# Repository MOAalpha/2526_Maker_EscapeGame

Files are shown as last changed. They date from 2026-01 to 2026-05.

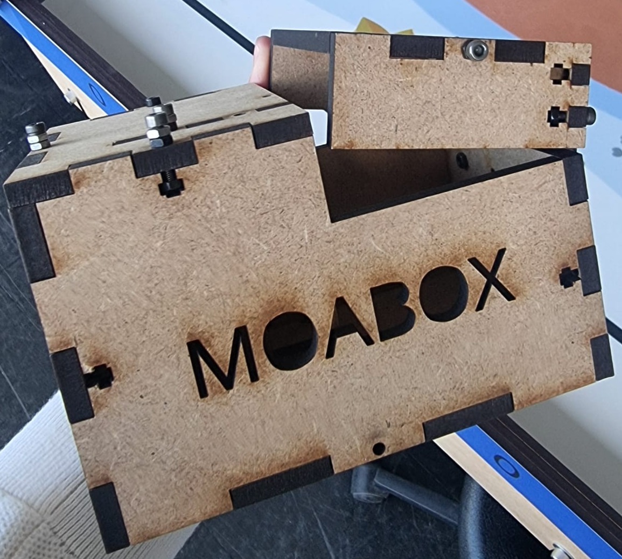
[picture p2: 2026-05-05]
LIVRABLES/USELESS_BOX.jpg

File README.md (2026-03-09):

Projet de GHERRAS M.A., dans le cadre de l'option MAKER 2526.
# **<u>EscapeGame</u>**

Ceci est un projet personnel. L'objectif est de créer une boîte avec différentes énigmes, en mettant en oeuvre différentes compétences apprises, entre la Conception Assistée par Ordinateur (CAO) jusqu'à la fabrication d'un PCB.

## Synopsis

*Une épidémie ravage le monde. Personne n'est à l'abri. Environ 10 000 000 de personnes succombent chaque seconde. Le virus possède une forte volatilité et tue en quelques jours. Le docteur Frank MaBoule, après avoir utilisé sa fille comme cobaye,  a créé un remède. Sa fille ayant succombé, il décida de cacher son remède.Sauriez-vous être le héros qui sauvera ~~le monde~~ votre peau ? Voici les épreuves qui vous attendent :*

### 1. FIND A CODE 
Pour ouvrir la première porte, il faut résoudre une énigme très classique consistant à reconstituer une séquence sur un damier de 4x4 symbolisé par 16 écrans.

### 2. DRESS or LESS 

Pour la deuxième porte, l'idée est de vêtir 3 personnages avec le bon chapeau, pull et pentalon, à l'aide de capteurs RFID. Pour cela, une description incomplète sera fournie à travers l'écran principale.

### 3. CHOOSE THE HERO

Parmi les 3 personnages, un seul cache le remède. Vous aurez leur témoignage pour savoir qui possède le remède.

## Matériel (liste actuelle non exhaustive):

> - 1 écran 15cmx10cm tactile (moniteur principale) [de ce type-là](https://www.amazon.fr/Tactile-Fabricant-Bricolage-Internet-%C3%A9lectrique/dp/B0BWNQKWJR)
> - 16 écrans de 4x4 ?
> - Actionneurs pour portes ? 
> - PLA pour les personnages
> - tissu pour les vêtements
> - ~Capteurs RFID miniatures ?~
> - [Capteurs magnétiques, reed switchs](https://www.amazon.fr/Gebildet-interrupteurs-Plastique-Contact-Aimant/dp/B07Z4RR4QV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)
> - *A suivre...*

## Planning prévisionnel 

| Séance | Action prévue |
|---|---|
| Lundi 16 février 2026 |  Conception des énigmes + Début schématique PCB |
| Jeudi 19 février 2026 | Choix des composants(Ecrans, Rasperry Pi/STM) + Suite PCB |
| Lundi 9 mars 2026 | Début conception mécanique (Plan de la boite, portes, personnages...) |
| Jeudi 12 mars 2026 | Découpe laser pour la boîte et premières impressions de pièces |
| Lundi 16 mars 2026 | Test PCB |
| Jeudi 19 mars 2026 | Setup capteurs RFID + Ecrans principales |
| Lundi 23 mars 2026 |  Améliorations + Correction |
| Jeudi 26 mars 2026 |  Code sur STM/Rasberry Pi |
| Lundi 30 mars 2026 | Tests / A voir |
| Jeudi 2 avril 2026 | A voir |
| Jeudi 9 avril 2026 |  Possibilité de rajouter des énigmes si tout fonctionne. / Création chatbot pour l'énigme des personnages si le temps le permet. |
| Lundi 13 avril 2026 | A voir |

GANTT : (*IA MADE, for visual*)

```mermaid

gantt
    title Planning du projet (février – avril 2026)
    dateFormat  YYYY-MM-DD
    axisFormat  %d/%m

    section Conception
    Conception des énigmes + schéma PCB         :a1, 2026-02-16, 3d
    Choix composants + suite PCB                :a2, after a1, 3d

    section Mécanique
    Conception mécanique (boîte, portes, persos):b1, 2026-03-09, 4d
    Découpe laser + impressions pièces          :b2, after b1, 3d

    section Électronique
    Test PCB                                    :c1, after a2, 2d
    Setup capteurs RFID + écrans principaux     :c2, after c1, 3d

    section Développement
    Améliorations + corrections                 :d1, after c2, 3d
    Code sur STM / Raspberry Pi                 :d2, after d1, 4d

    section Tests & ajustements
    Tests généraux                              :e1, after d2, 3d
    Ajustements techniques                     :e2, after e1, 3d

    section Extensions (optionnel)
    Ajout d’énigmes / chatbot personnages       :f1, after e2, 4d

    section Final
    Finalisation & préparation soutenance       :g1, after f1, 2d

```

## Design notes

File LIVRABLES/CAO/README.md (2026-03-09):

Voici les captures d'écran des éléments réalisés sur Onshape : https://cad.onshape.com/documents/aa734c8ff76d5fbc18c7c107/w/db248731c732559cfe28cdcf/e/f61cb79261a09111bf038288

> - Protections Coins : 

Capture d'écran 2026-01-21 232816

> - Support téléphone : 

 Capture d'écran 2026-01-21 232552

> - Torticolis : 
Capture d'écran 2026-01-21 232736

> - Ciseaux : 
Capture d'écran 2026-01-21 232327

> - Ressort :
Capture d'écran 2026-01-21 232856

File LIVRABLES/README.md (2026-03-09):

Stockage des travaux effectués (et présentables) pendant les séances "Découverte"

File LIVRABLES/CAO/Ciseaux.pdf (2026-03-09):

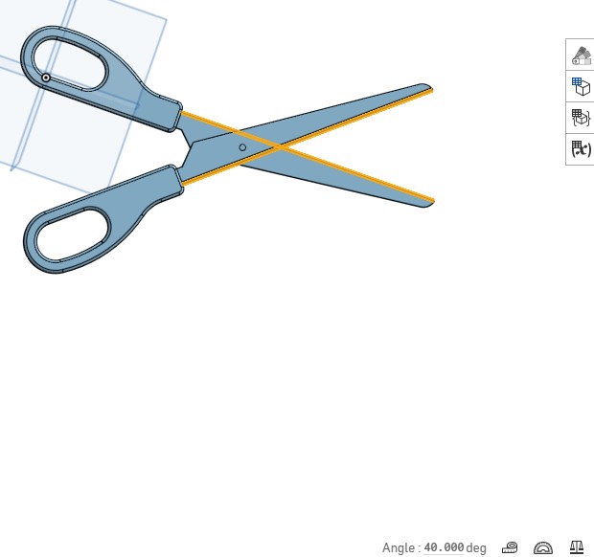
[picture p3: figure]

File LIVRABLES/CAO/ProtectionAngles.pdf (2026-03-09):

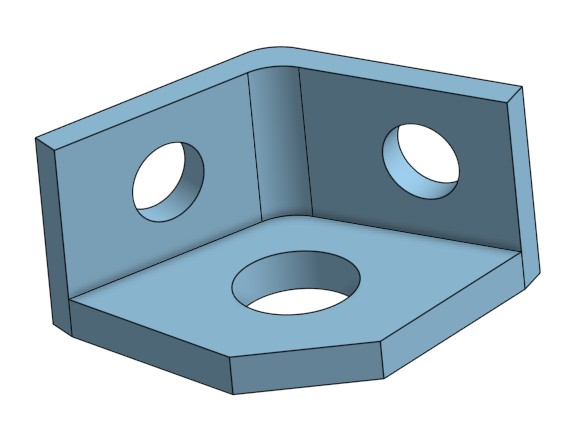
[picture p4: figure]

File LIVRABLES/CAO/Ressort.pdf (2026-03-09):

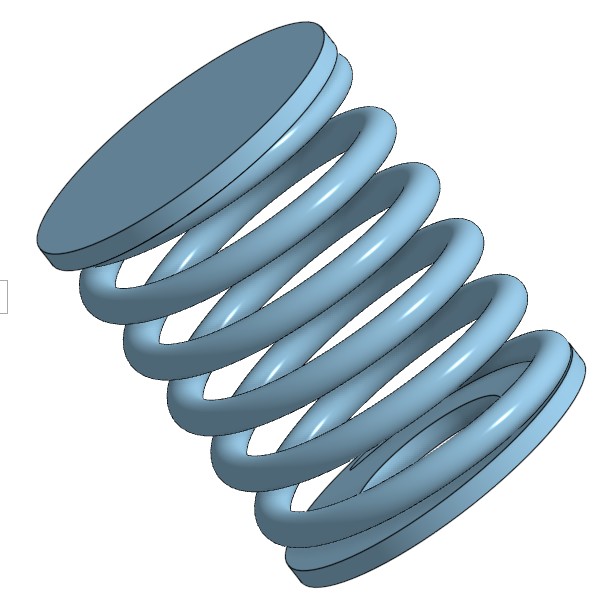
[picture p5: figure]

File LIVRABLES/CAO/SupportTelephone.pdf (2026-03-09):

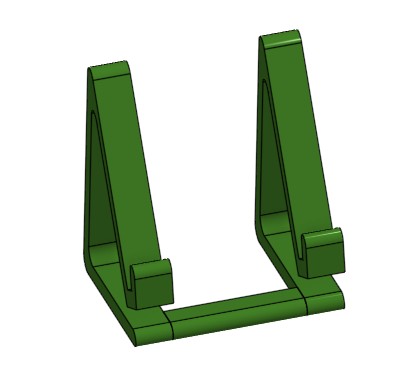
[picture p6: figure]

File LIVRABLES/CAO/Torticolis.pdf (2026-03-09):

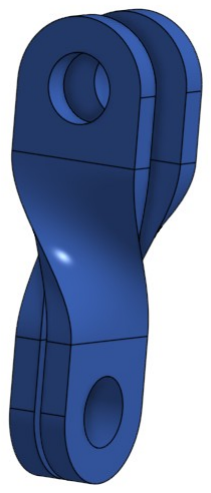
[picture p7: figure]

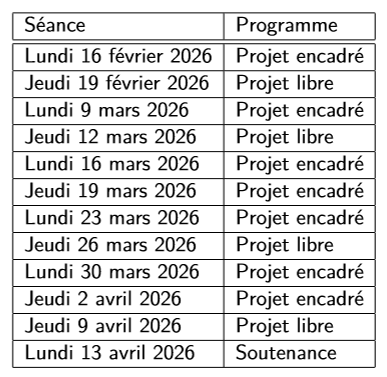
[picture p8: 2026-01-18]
image.png

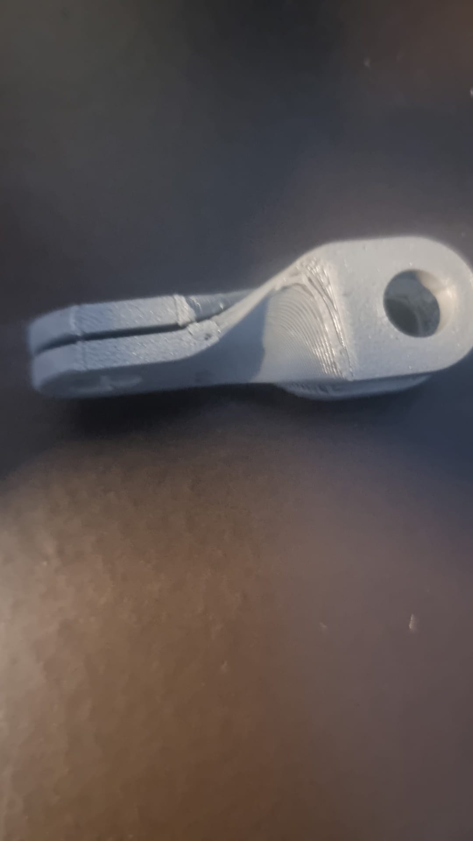
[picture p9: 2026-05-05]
LIVRABLES/Impression3D-Face2.jpeg

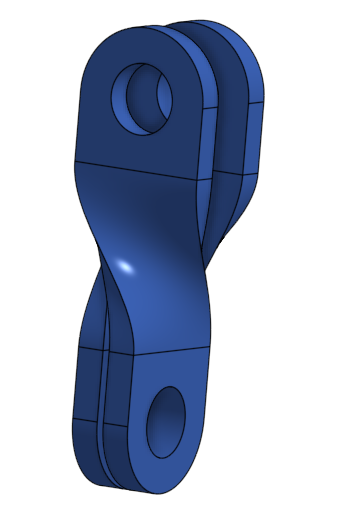
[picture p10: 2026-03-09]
LIVRABLES/CAO/Capture d'écran 2026-01-21 232736.png

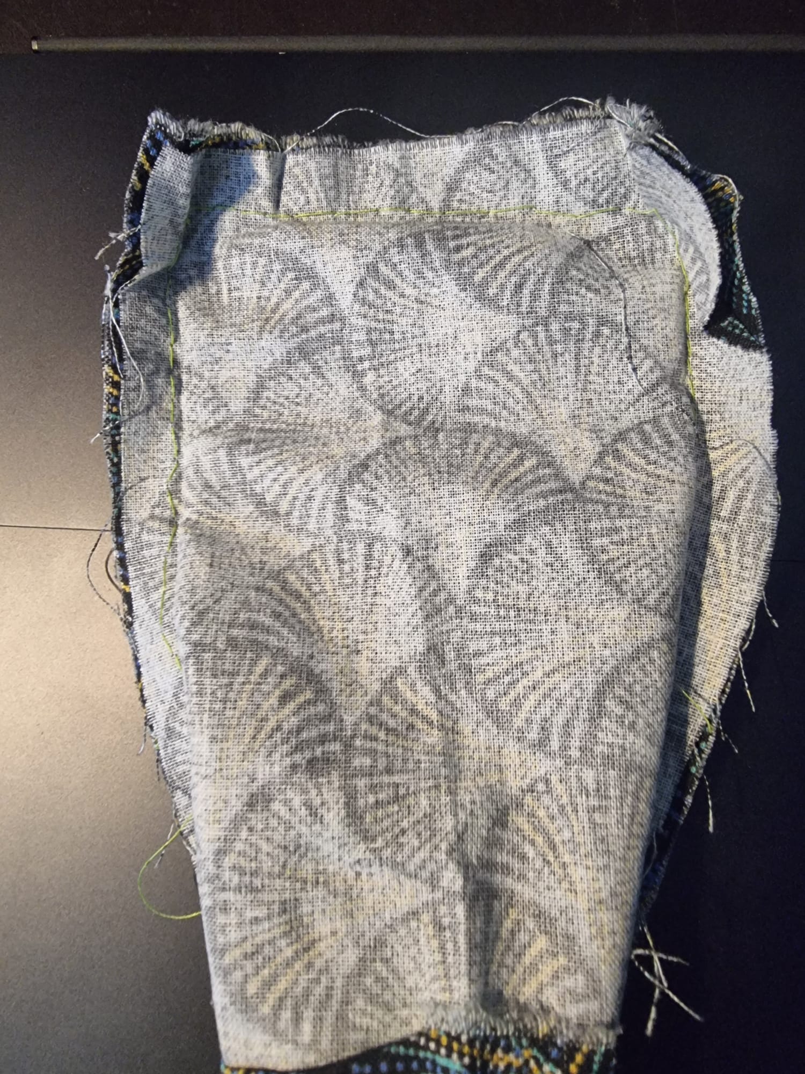
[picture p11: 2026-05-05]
LIVRABLES/Couture-Intérieur.jpeg

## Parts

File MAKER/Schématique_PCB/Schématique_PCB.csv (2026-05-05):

Reference | Qty | Value | DNP | Exclude from BOM | Exclude from Board | Footprint | Datasheet
C1,C2,C9,C10 | 4 | 1u |  |  |  | Capacitor_SMD:C_0805_2012Metric_Pad1.18x1.45mm_HandSolder | ~
C3,C4,C5,C6,C18 | 5 | 100n |  |  |  | Capacitor_SMD:C_0805_2012Metric_Pad1.18x1.45mm_HandSolder | ~
C7 | 1 | 4.7u |  |  |  | Capacitor_SMD:C_0805_2012Metric_Pad1.18x1.45mm_HandSolder | ~
C8,C11,C12,C13,C14,C15,C16,C19 | 8 | 10n |  |  |  | Capacitor_SMD:C_0805_2012Metric_Pad1.18x1.45mm_HandSolder | ~
C17 | 1 | 10u |  |  |  | Capacitor_SMD:C_0805_2012Metric_Pad1.18x1.45mm_HandSolder | ~
D1,D2 | 2 | LED |  |  |  | LED_SMD:LED_0805_2012Metric_Pad1.15x1.40mm_HandSolder | ~
H1,H2,H3,H4 | 4 | MountingHole_Pad |  | Exclure de la Liste du Matériel |  | MountingHole:MountingHole_3.2mm_M3_DIN965_Pad | ~
J1 | 1 | TS1 |  |  |  | Connector_PinHeader_2.54mm:PinHeader_1x03_P2.54mm_Vertical | ~
J2 | 1 | 3.7V |  |  |  | Connector_JST:JST_PH_B2B-PH-K_1x02_P2.00mm_Vertical | ~
J3 | 1 | TS2 |  |  |  | Connector_PinHeader_2.54mm:PinHeader_1x03_P2.54mm_Vertical | ~
J4 | 1 | TS3 |  |  |  | Connector_PinHeader_2.54mm:PinHeader_1x03_P2.54mm_Vertical | ~
J5 | 1 | TS4 |  |  |  | Connector_PinHeader_2.54mm:PinHeader_1x03_P2.54mm_Vertical | ~
J6 | 1 | TS5 |  |  |  | Connector_PinHeader_2.54mm:PinHeader_1x03_P2.54mm_Vertical | ~
J7 | 1 | TS6 |  |  |  | Connector_PinHeader_2.54mm:PinHeader_1x03_P2.54mm_Vertical | ~
J8 | 1 | TS7 |  |  |  | Connector_PinHeader_2.54mm:PinHeader_1x03_P2.54mm_Vertical | ~
J9 | 1 | TS8 |  |  |  | Connector_PinHeader_2.54mm:PinHeader_1x03_P2.54mm_Vertical | ~
J10 | 1 | TS9 |  |  |  | Connector_PinHeader_2.54mm:PinHeader_1x03_P2.54mm_Vertical | ~
J11,J12,J13,J14,J15,J16 | 6 | Conn_01x02_Pin |  |  |  | Connector_PinHeader_2.54mm:PinHeader_1x02_P2.54mm_Vertical | ~
J17 | 1 | Screen |  |  |  | Connector_PinSocket_2.54mm:PinSocket_1x09_P2.54mm_Vertical | ~
J18 | 1 | SD_Card |  |  |  | Connector_PinSocket_2.54mm:PinSocket_1x05_P2.54mm_Vertical | ~
J19 | 1 | Conn_ST_STDC14 |  |  |  | Connector_IDC:IDC-Header_2x07_P2.54mm_Vertical | https://www.st.com/content/ccc/resource/technical/document/user_manual/group1/99/49/91/b6/b2/3a/46/e5/DM00526767/files/DM00526767.pdf/jcr:content/translations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
PS1 | 1 | BU33SD5WG-TR |  |  |  | BU33SD5WG-TR:SOT95P280X125-5N
R1,R3 | 2 | 330 |  |  |  | Resistor_SMD:R_0805_2012Metric_Pad1.20x1.40mm_HandSolder | ~
R2,R12,R13,R14,R15,R16 | 6 | 1K |  |  |  | Resistor_SMD:R_0805_2012Metric_Pad1.20x1.40mm_HandSolder | ~
R4,R5,R6,R7,R8,R9 | 6 | 100 |  |  |  | Resistor_SMD:R_0805_2012Metric_Pad1.20x1.40mm_HandSolder | ~
R10,R11 | 2 | 10k |  |  |  | Resistor_SMD:R_0805_2012Metric_Pad1.20x1.40mm_HandSolder | ~
SW1 | 1 | SW_Push |  |  |  | Button_Switch_SMD:SW_SPST_B3U-1000P | ~
U1 | 1 | STM32G474RET6 |  |  |  | Package_QFP:LQFP-64_10x10mm_P0.5mm | https://www.st.com/resource/en/datasheet/stm32g474re.pdf

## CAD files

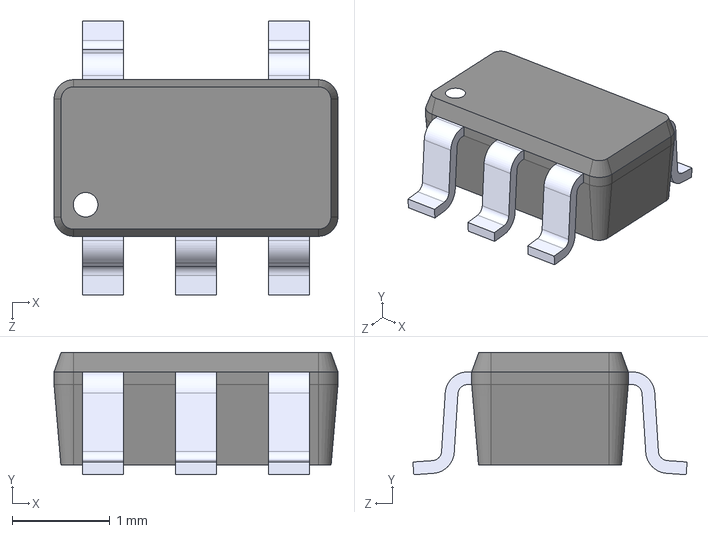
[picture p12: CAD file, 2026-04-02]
MAKER/Symbols/BU33SD5WG-TR/BU33SD5WG-TR.step
2.90 x 1.25 x 2.80 mm

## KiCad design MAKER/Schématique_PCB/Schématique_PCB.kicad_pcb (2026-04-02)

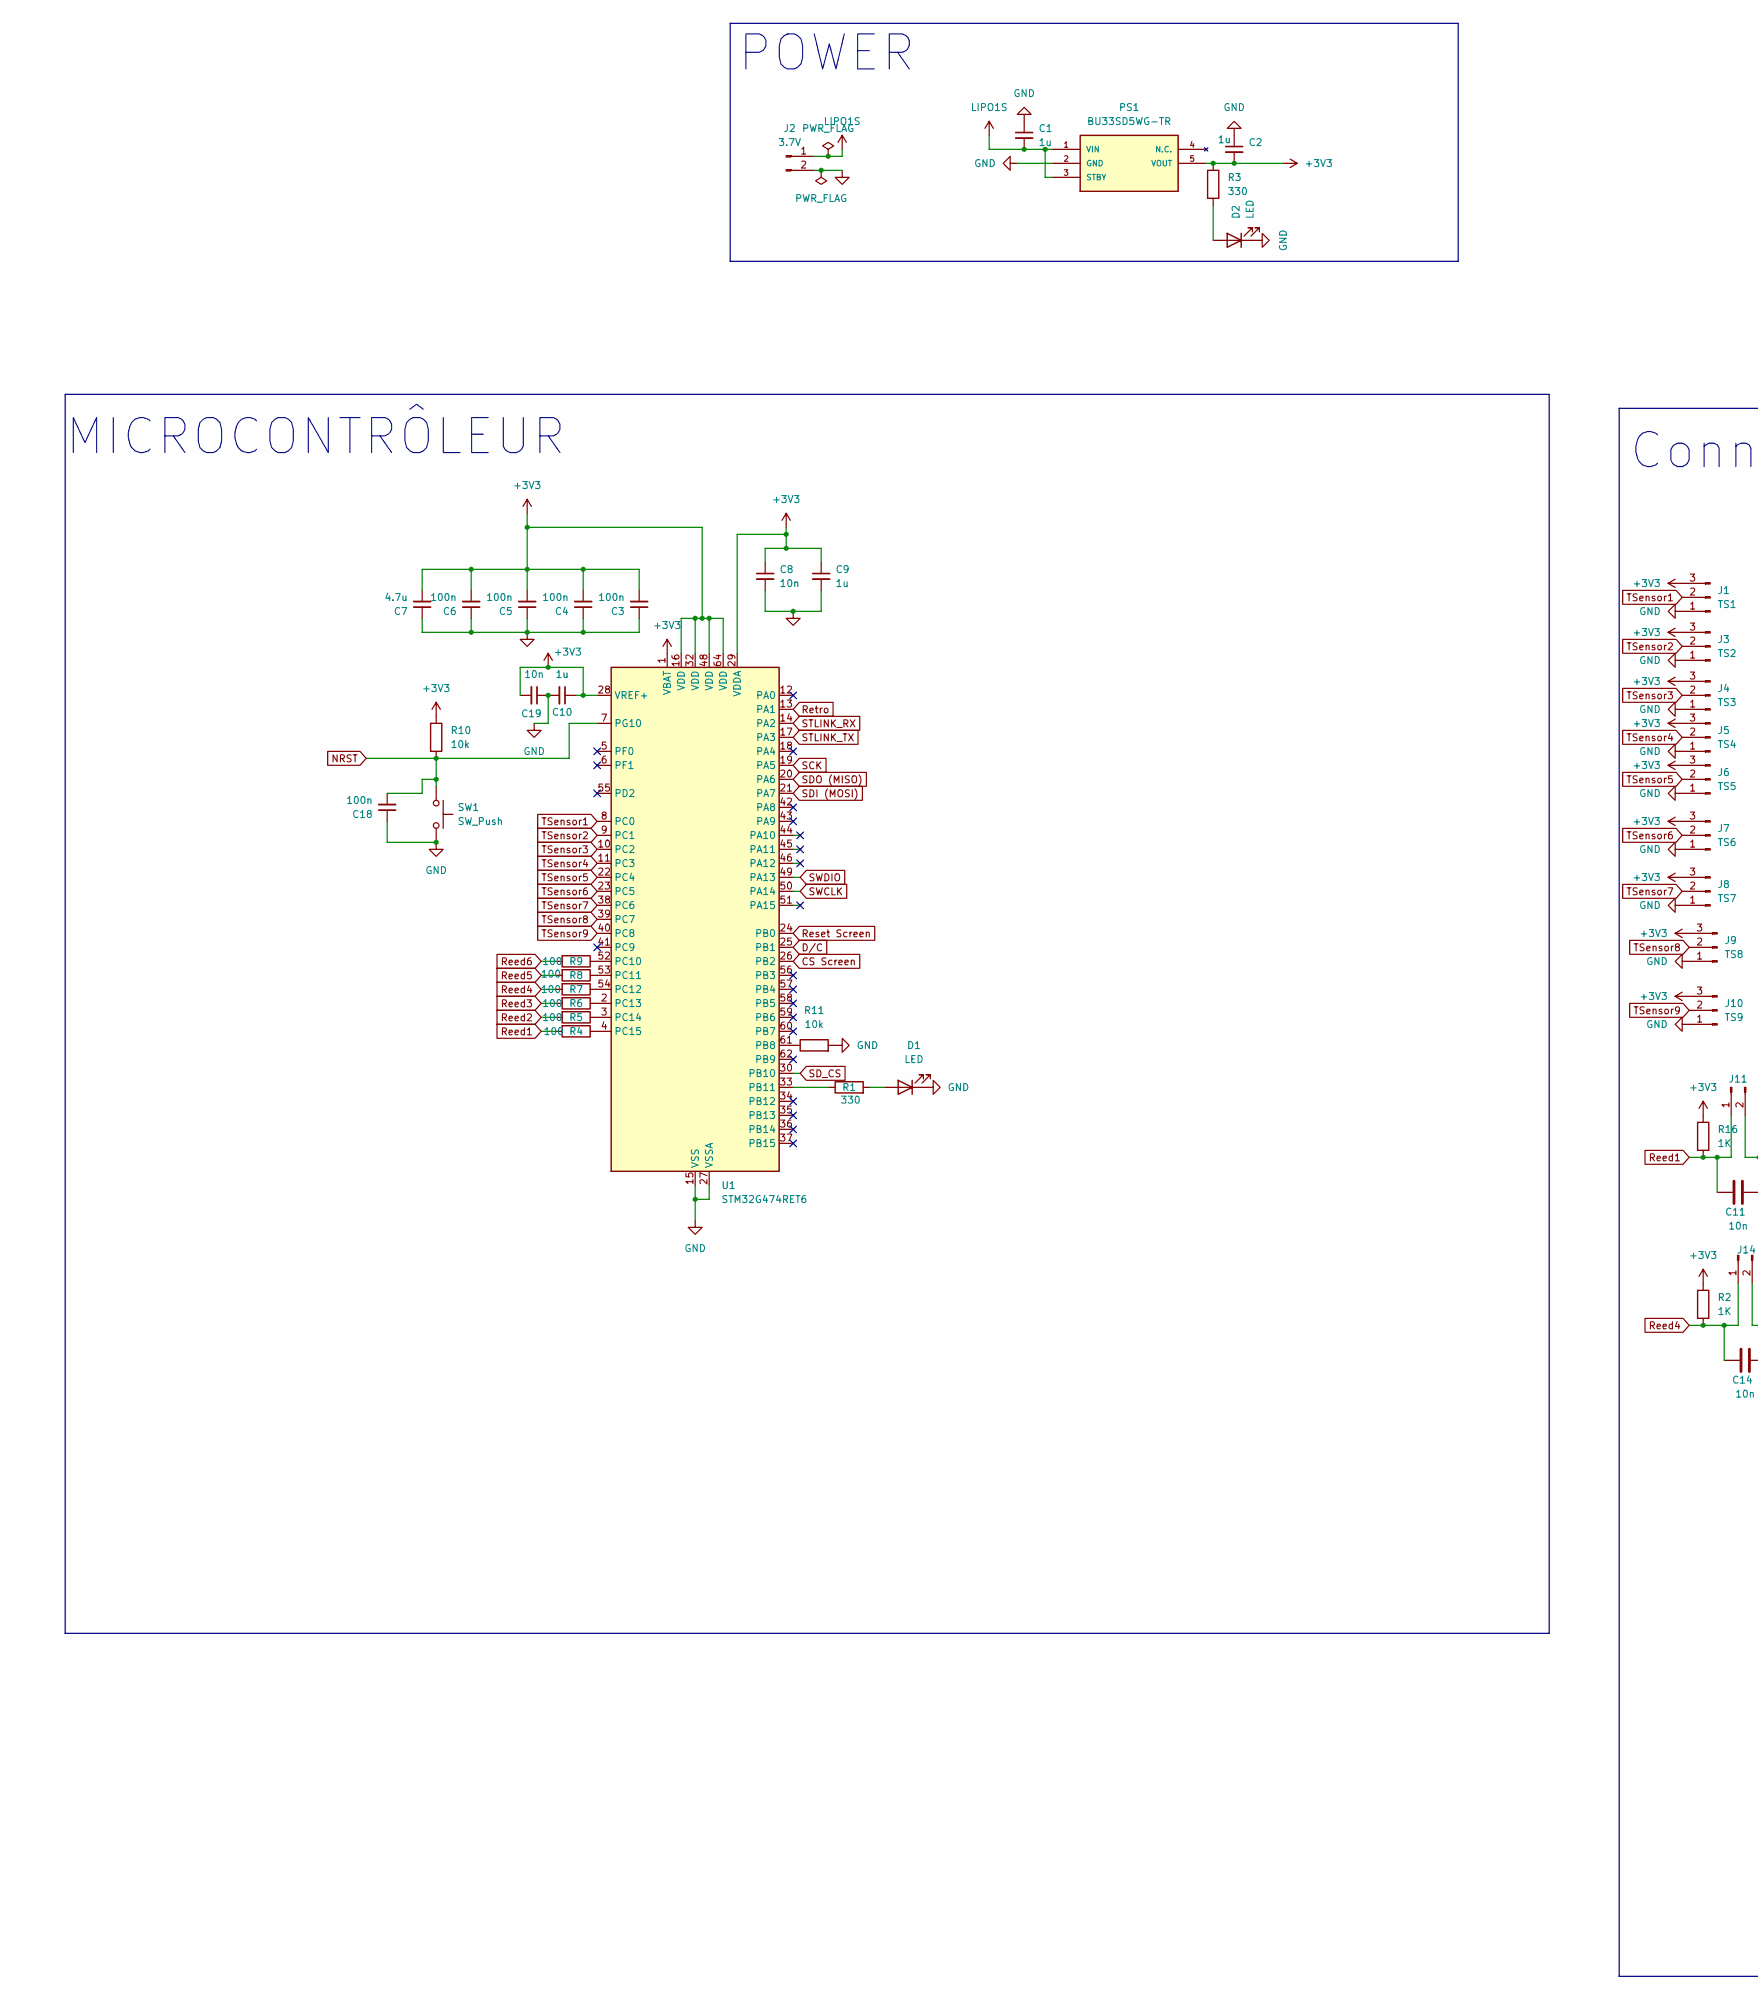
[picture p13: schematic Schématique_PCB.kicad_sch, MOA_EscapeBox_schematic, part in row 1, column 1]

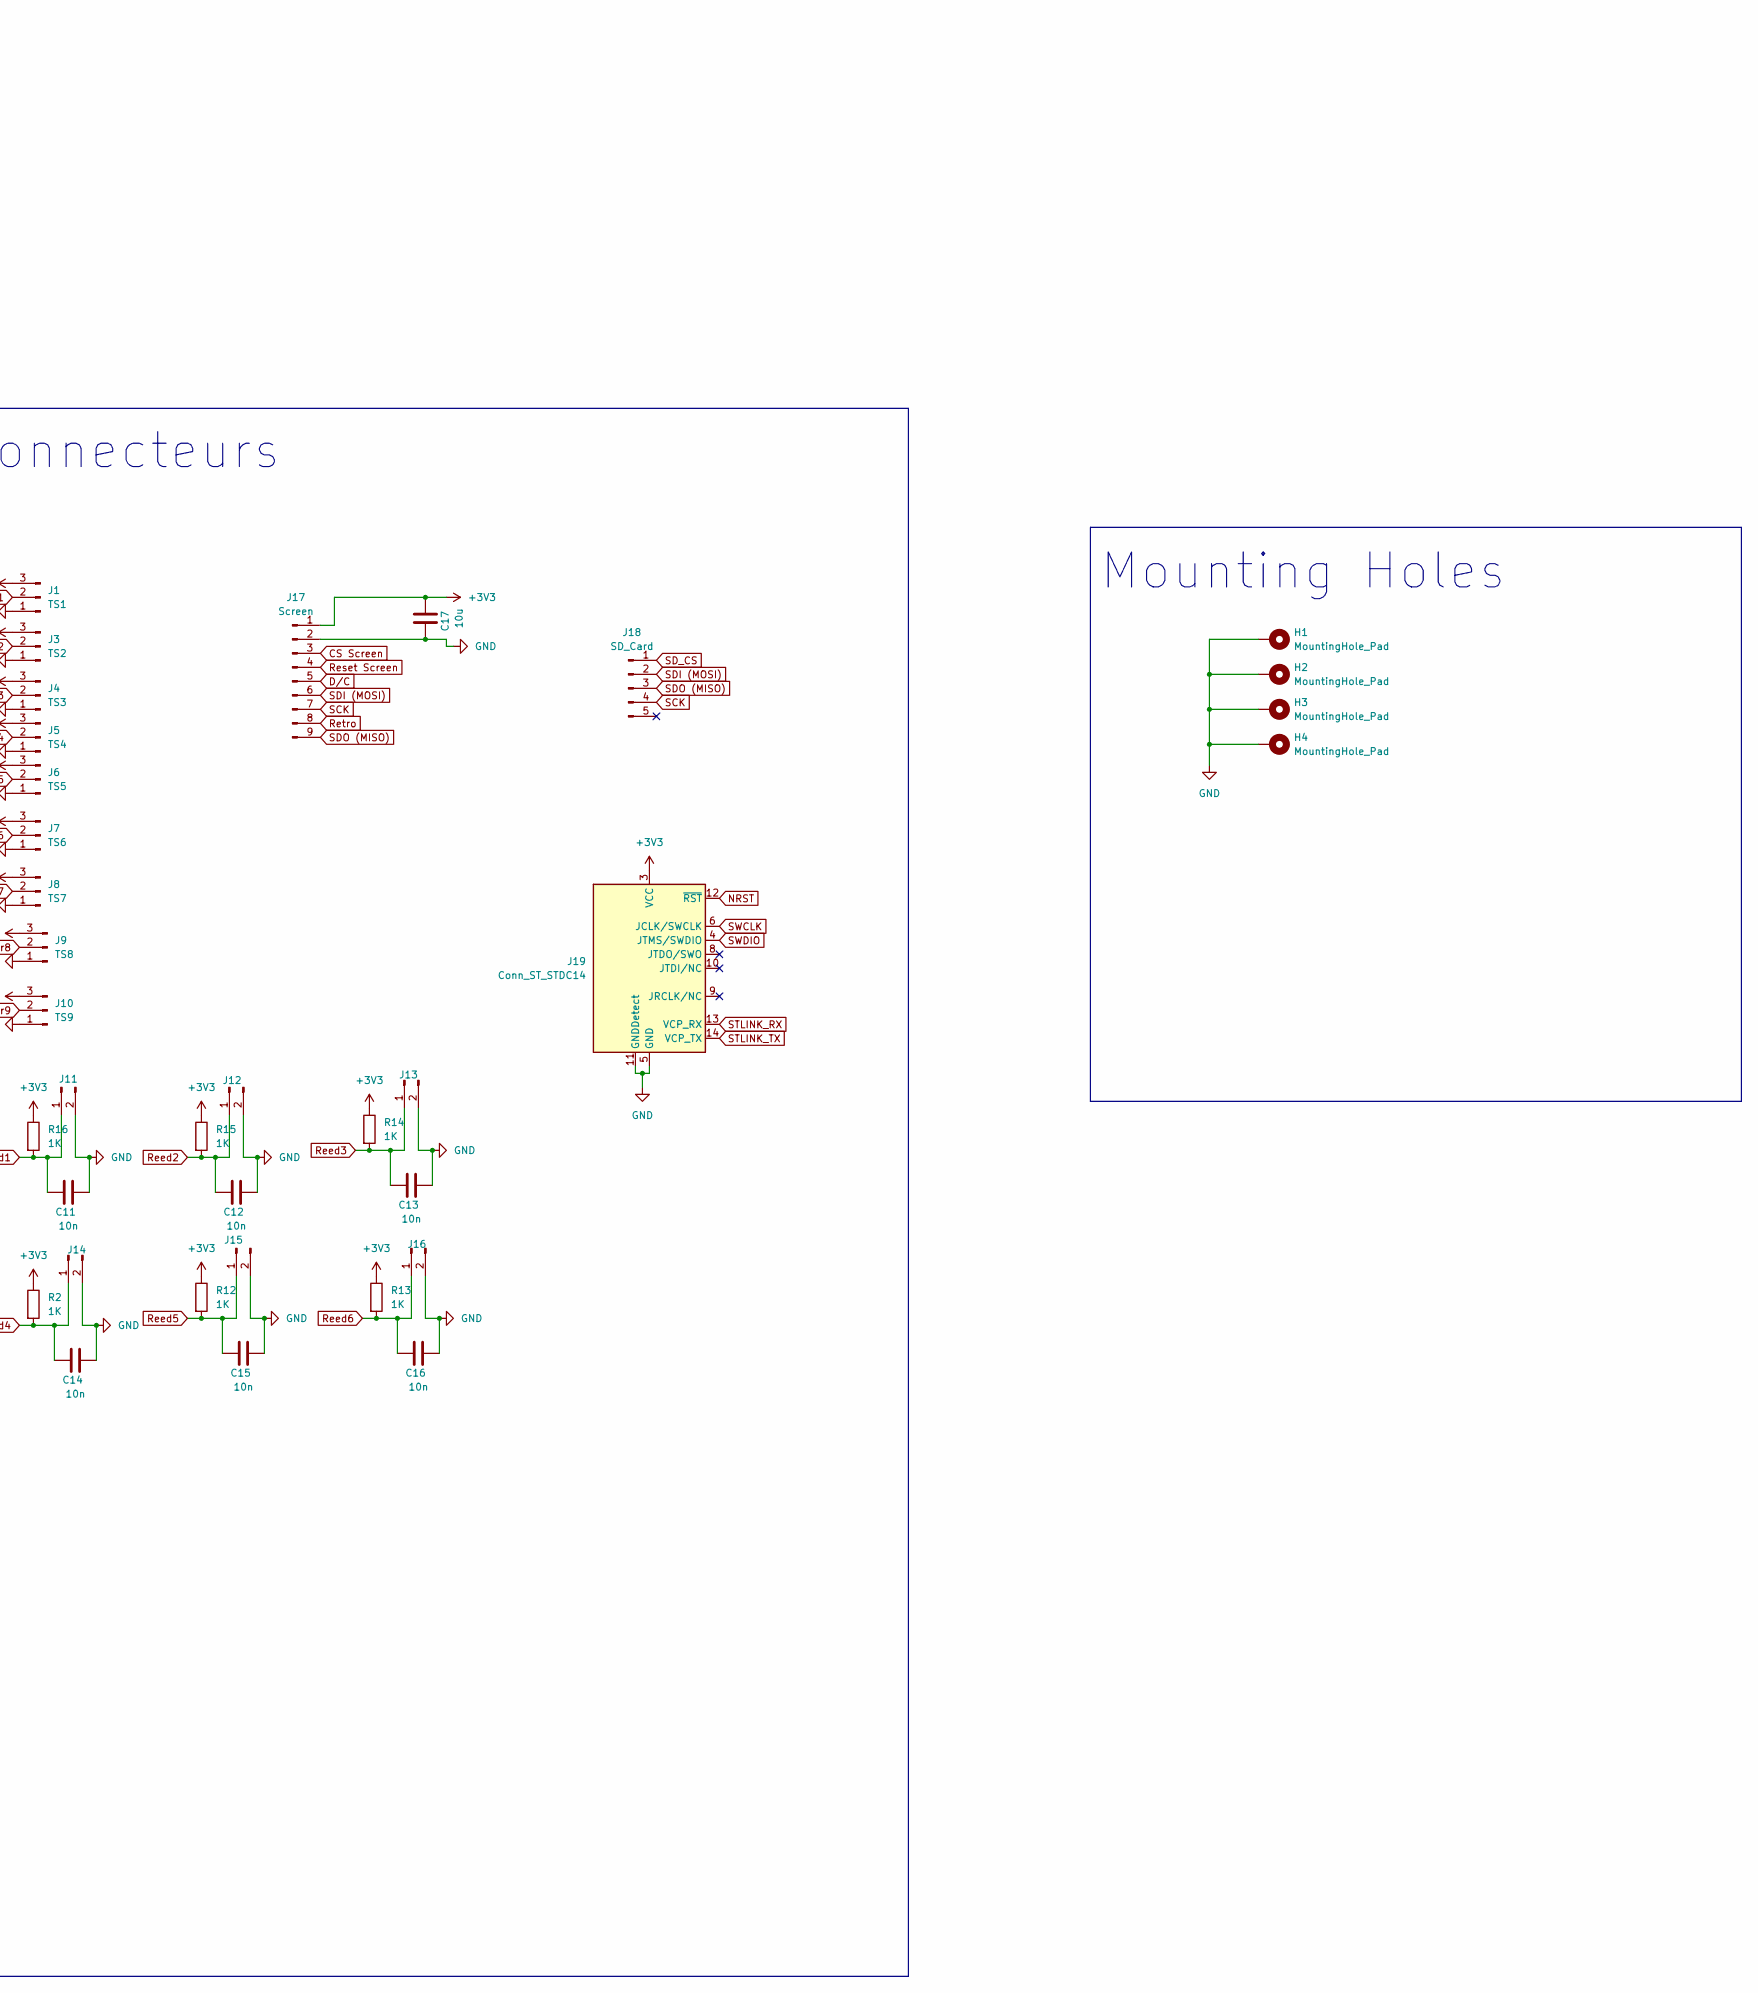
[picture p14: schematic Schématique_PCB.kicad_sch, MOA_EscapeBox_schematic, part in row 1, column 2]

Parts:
C1, C2, C9, C10: 1u; C_0805_2012Metric_Pad1.18x1.45mm_HandSolder
C3, C4, C5, C6, C18: 100n; C_0805_2012Metric_Pad1.18x1.45mm_HandSolder
C7: 4.7u; C_0805_2012Metric_Pad1.18x1.45mm_HandSolder
C8, C11, C12, C13, C14, C15, C16, C19: 10n; C_0805_2012Metric_Pad1.18x1.45mm_HandSolder
C17: 10u; C_0805_2012Metric_Pad1.18x1.45mm_HandSolder
D1, D2: LED; LED_0805_2012Metric_Pad1.15x1.40mm_HandSolder
H1, H2, H3, H4: MountingHole_Pad; MountingHole_3.2mm_M3_DIN965_Pad
J1: TS1; PinHeader_1x03_P2.54mm_Vertical
J2: 3.7V; JST_PH_B2B-PH-K_1x02_P2.00mm_Vertical
J3: TS2; PinHeader_1x03_P2.54mm_Vertical
J4: TS3; PinHeader_1x03_P2.54mm_Vertical
J5: TS4; PinHeader_1x03_P2.54mm_Vertical
J6: TS5; PinHeader_1x03_P2.54mm_Vertical
J7: TS6; PinHeader_1x03_P2.54mm_Vertical
J8: TS7; PinHeader_1x03_P2.54mm_Vertical
J9: TS8; PinHeader_1x03_P2.54mm_Vertical
J10: TS9; PinHeader_1x03_P2.54mm_Vertical
J11, J12, J13, J14, J15, J16: Conn_01x02_Pin; PinHeader_1x02_P2.54mm_Vertical
J17: Screen; PinSocket_1x09_P2.54mm_Vertical
J18: SD_Card; PinSocket_1x05_P2.54mm_Vertical
J19: Conn_ST_STDC14; IDC-Header_2x07_P2.54mm_Vertical
PS1: BU33SD5WG-TR; SOT95P280X125-5N; Mouser_Part_Number 755-BU33SD5WG-TR
R1, R3: 330; R_0805_2012Metric_Pad1.20x1.40mm_HandSolder
R2, R12, R13, R14, R15, R16: 1K; R_0805_2012Metric_Pad1.20x1.40mm_HandSolder
R4, R5, R6, R7, R8, R9: 100; R_0805_2012Metric_Pad1.20x1.40mm_HandSolder
R10, R11: 10k; R_0805_2012Metric_Pad1.20x1.40mm_HandSolder
SW1: SW_Push; SW_SPST_B3U-1000P
U1: STM32G474RET6; LQFP-64_10x10mm_P0.5mm

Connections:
+3V3: C2.2, C3.2, C4.2, C5.2, C6.2, C7.2, C8.1, C9.1, C10.1, C17.2, C19.2, J1.3, J3.3, J4.3, J5.3, J6.3, J7.3, J8.3, J9.3, J10.3, J17.1, J19.3 (VCC), PS1.5 (VOUT), R2.1, R3.1, R10.1, R12.1, R13.1, R14.1, R15.1, R16.1, U1.1 (VBAT), U1.16 (VDD), U1.28 (VREF+), U1.29 (VDDA), U1.32 (VDD), U1.48 (VDD), U1.64 (VDD)
CS Screen: J17.3, U1.26 (PB2)
D/C: J17.5, U1.25 (PB1)
GND: C1.1, C2.1, C3.1, C4.1, C5.1, C6.1, C7.1, C8.2, C9.2, C10.2, C11.2, C12.2, C13.2, C14.2, C15.2, C16.2, C17.1, C18.1, C19.1, D1.1 (K), D2.1 (K), H1.1, H2.1, H3.1, H4.1, J1.1, J2.2, J3.1, J4.1, J5.1, J6.1, J7.1, J8.1, J9.1, J10.1, J11.2, J12.2, J13.2, J14.2, J15.2, J16.2, J17.2, J19.5 (GND), J19.7 (GND), J19.11 (GNDDetect), PS1.2 (GND), R11.2, SW1.2, U1.15 (VSS), U1.27 (VSSA), U1.31 (VSS), U1.47 (VSS), U1.63 (VSS)
LIPO1S: C1.2, J2.1, PS1.1 (VIN), PS1.3 (STBY)
NRST: C18.2, J19.12 (~RST), R10.2, SW1.1, U1.7 (PG10)
unnamed: D1.2 (A), R1.2
unnamed: D2.2 (A), R3.2
unnamed: R11.1, U1.61 (PB8)
unnamed: R1.1, U1.33 (PB11)
unnamed: R9.1, U1.52 (PC10)
unnamed: R8.1, U1.53 (PC11)
unnamed: R7.1, U1.54 (PC12)
unnamed: R6.1, U1.2 (PC13)
unnamed: R5.1, U1.3 (PC14)
unnamed: R4.1, U1.4 (PC15)
Reed1: C11.1, J11.1, R4.2, R16.2
Reed2: C12.1, J12.1, R5.2, R15.2
Reed3: C13.1, J13.1, R6.2, R14.2
Reed4: C14.1, J14.1, R2.2, R7.2
Reed5: C15.1, J15.1, R8.2, R12.2
Reed6: C16.1, J16.1, R9.2, R13.2
Reset Screen: J17.4, U1.24 (PB0)
Retro: J17.8, U1.13 (PA1)
SCK: J17.7, J18.4, U1.19 (PA5)
SDI (MOSI): J17.6, J18.2, U1.21 (PA7)
SDO (MISO): J17.9, J18.3, U1.20 (PA6)
SD_CS: J18.1, U1.30 (PB10)
STLINK_RX: J19.13 (VCP_RX), U1.14 (PA2)
STLINK_TX: J19.14 (VCP_TX), U1.17 (PA3)
SWCLK: J19.6 (JCLK/SWCLK), U1.50 (PA14)
SWDIO: J19.4 (JTMS/SWDIO), U1.49 (PA13)
TSensor1: J1.2, U1.8 (PC0)
TSensor2: J3.2, U1.9 (PC1)
TSensor3: J4.2, U1.10 (PC2)
TSensor4: J5.2, U1.11 (PC3)
TSensor5: J6.2, U1.22 (PC4)
TSensor6: J7.2, U1.23 (PC5)
TSensor7: J8.2, U1.38 (PC6)
TSensor8: J9.2, U1.39 (PC7)
TSensor9: J10.2, U1.40 (PC8)

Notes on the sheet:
POWER
Mounting Holes
Connecteurs
MICROCONTRÔLEUR

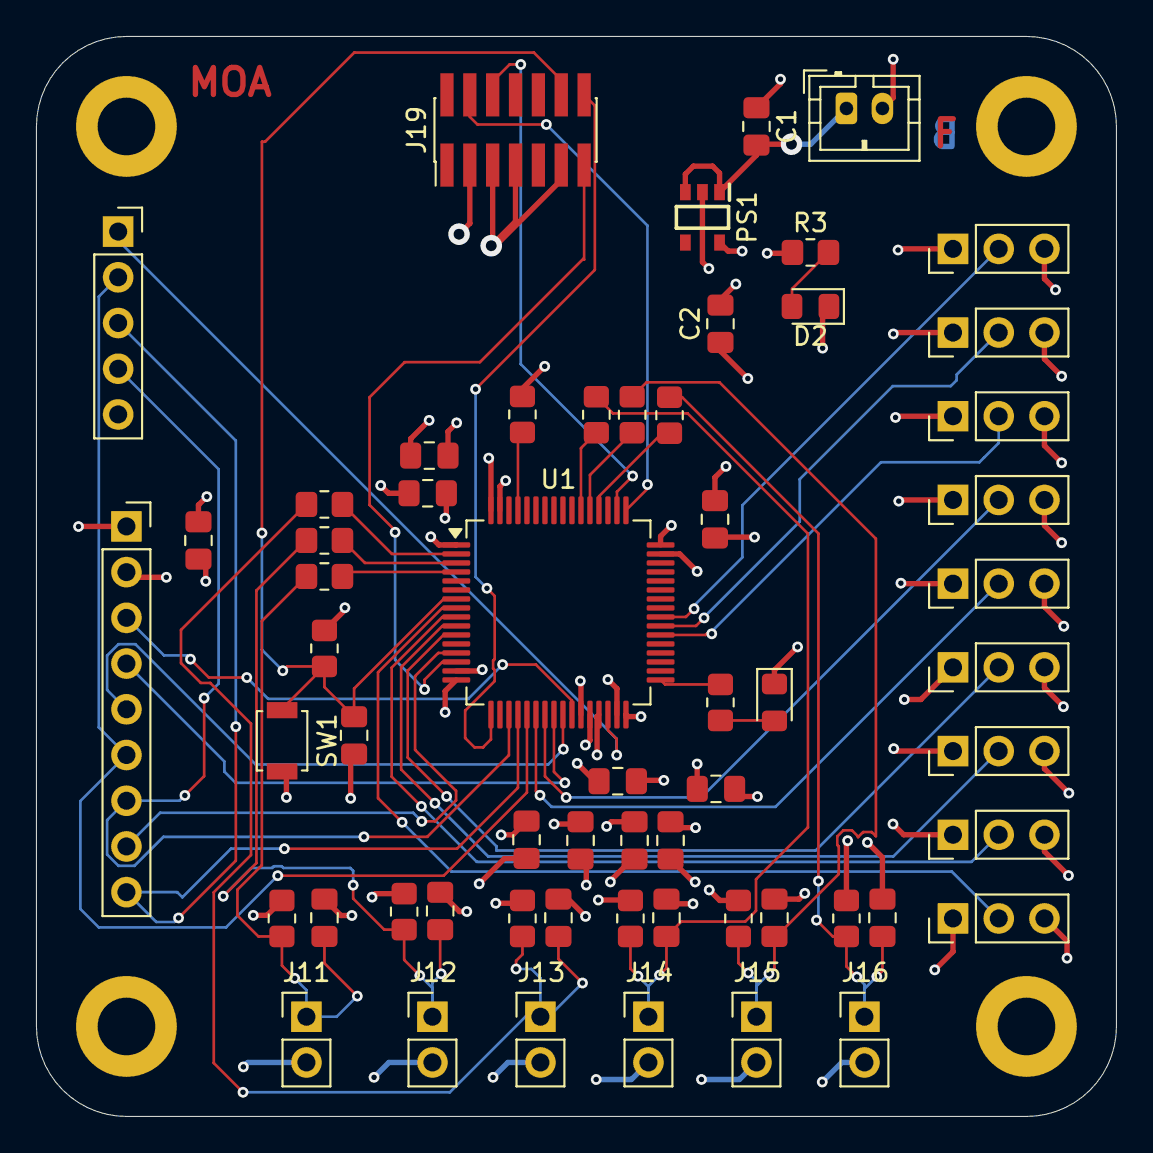
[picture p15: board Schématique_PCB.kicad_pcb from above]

Board: 4 copper layers, 60.0 x 60.0 mm, 63 parts (0 on the bottom side), 41 nets.

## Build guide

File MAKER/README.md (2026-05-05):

RQ : Remplacement des cartes RFID (16 capteurs) par des touch sensors TTP223 (9)

> *« Ici seront contées les aventures de ce projet. »*

> - **Liste de matériel** :\
      - [Interrupteur Tactile TTP223](https://www.amazon.fr/JZK-modules-tactiles-capacitifs-auto-bloquants/dp/B09VPK9N7F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)\
      - [Capteur Reed (I2L)](https://www.amazon.fr/Gebildet-interrupteurs-Plastique-Contact-Aimant/dp/B07Z4RR4QV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 )\
      - [Ecran Tactile](https://www.amazon.fr/Module-daffichage-Tactile-Support-Fonction/dp/B07PKB691V?th=1)

> 1. **Lundi 16 février :** Première séance du projet.
>   - Recherche de composants/solutions pour la 3e énigme
>     - Choix des [reed switch](https://www.amazon.fr/Gebildet-interrupteurs-Plastique-Contact-Aimant/dp/B07Z4RR4QV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)
>   - Début de conception [Personnage](https://cad.onshape.com/documents/36c05aa2ce0a4fdcf2218e35/w/67816f6025d3e2feaa42b7d7/e/d2e63ed0c857ded856796908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)

> 2. **Lundi 9 mars :**
>   - Recherche de composants pour la 1ere énigme : 
>     - Découverte des [interrupteurs tactiles TTP223](https://www.amazon.fr/JZK-modules-tactiles-capacitifs-auto-bloquants/dp/B09VPK9N7F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)
>   - Choix de la [STM32G474RET6](https://www.mouser.fr/ProductDetail/STMicroelectronics/STM32G474RET6?qs=PzGy0jfpSMvUBs7PMTDqlg%3D%3D)
>   - Choix de l'écran : [Affichage LCD TFT Couleur Tactile de 3,2 po.](https://www.amazon.fr/Module-daffichage-Tactile-Support-Fonction/dp/B07PKB691V?th=1)
>   - Recherche code Ecran : [Electrocodeur](https://youtu.be/JoLnnLlXwX0)

> ...
> **Semaine XX : Death time**
> - Impressions des personnages pour la 2e énigme
> - Découpe de la boîte, avec une petite gravure
> - Conception PCB, puis soudure au four
> - Soudure ratée (pâtes soudées entre elles, plus manque d'une lipo Simple)
> - Test avec Nucleo pour l'écran et 2 TTP (fonctionne bien)

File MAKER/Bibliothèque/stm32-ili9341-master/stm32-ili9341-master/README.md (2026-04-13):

# stm32-ili9341

STM32 HAL-based library for ILI9341 TFT modules with touchscreen.

This library is based on [afiskon/stm32-st7735][u1] and
[afiskon/stm32-ssd1306][u2]. Initialization sequence for ILI9341 was borrowed
from [martnak/STM32-ILI9341][u3].

See also:

* https://github.com/afiskon/stm32-i2c-lcd-1602
* https://github.com/afiskon/stm32-ssd1306
* https://github.com/afiskon/stm32-ssd1351
* https://github.com/afiskon/stm32-st7735

[u1]: https://github.com/afiskon/stm32-st7735
[u2]: https://github.com/afiskon/stm32-ssd1306
[u3]: https://github.com/martnak/STM32-ILI9341

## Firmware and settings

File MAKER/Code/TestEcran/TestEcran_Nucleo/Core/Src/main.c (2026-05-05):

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
/* Includes ------------------------------------------------------------------*/
#include "main.h"

/* USER CODE BEGIN Includes */
#include "ili9341.h"
#include "fonts.h"
#include "myutils.h"
/* USER CODE END Includes */

RNG_HandleTypeDef hrng;

SPI_HandleTypeDef hspi2;

UART_HandleTypeDef huart2;

/* USER CODE BEGIN PV */
extern volatile uint8_t start_game_flag;
extern volatile uint8_t touche_TTP;
/* USER CODE END PV */

void SystemClock_Config(void);
static void MX_GPIO_Init(void);
static void MX_SPI2_Init(void);
static void MX_USART2_UART_Init(void);
static void MX_RNG_Init(void);
/**
  * @brief  The application entry point.
  * @retval int
  */
int main(void)
{

  /* MCU Configuration--------------------------------------------------------*/

  /* Reset of all peripherals, Initializes the Flash interface and the Systick. */
  HAL_Init();

  /* Configure the system clock */
  SystemClock_Config();

  /* Initialize all configured peripherals */
  MX_GPIO_Init();
  MX_SPI2_Init();
  MX_USART2_UART_Init();
  MX_RNG_Init();
  /* USER CODE BEGIN 2 */
  //ILI9341_Unselect(); // On s'assure que l'écran est libéré au départ
  ILI9341_Init(); // Allume l'écran et configure les registres
  ILI9341_FillScreen(ILI9341_RED); // Remplit l'écran en rouge pour vérifier que ça marche
  ILI9341_SetRotation(3);
  ILI9341_WriteString(10, 10, "Bienvenue sur la MOA ESCAPE BOX (MEB) !", Font_11x18, ILI9341_BLACK, ILI9341_WHITE);// Un petit message
  HAL_Delay(2000);

  //Début de l'histoire:
  start_story();
  /* USER CODE END 2 */

  /* Infinite loop */
  /* USER CODE BEGIN WHILE */
  while (1)
  {
    /* USER CODE END WHILE */

    /* USER CODE BEGIN 3 */

  }
  /* USER CODE END 3 */
}

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
/* USER CODE BEGIN 4 */

void HAL_GPIO_EXTI_Callback(uint16_t GPIO_Pin)
{
    if(GPIO_Pin == B1_Pin) // On vérifie que c'est bien le bon bouton
    {
        // Ton code ici (ex: changer une variable d'état pour passer à l'étape suivante)
        // ATTENTION : Ne mets JAMAIS de HAL_Delay() ou de fonctions d'écriture LCD longues ici !

        static uint32_t last_interrupt_time = 0;
        uint32_t interrupt_time = HAL_GetTick();

        // Anti-rebond (Debounce) logiciel simple : 200ms
        if (interrupt_time - last_interrupt_time > 200)
        {
            // Action à faire, par exemple :
            start_game_flag = 1;
        }
        last_interrupt_time = interrupt_time;

    }
    if(GPIO_Pin == TTP_0_Pin){
    	 // Ton code ici (ex: changer une variable d'état pour passer à l'étape suivante)
    	        // ATTENTION : Ne mets JAMAIS de HAL_Delay() ou de fonctions d'écriture LCD longues ici !

    	        static uint32_t last_interrupt_time = 0;
    	        uint32_t interrupt_time = HAL_GetTick();

    	        // Anti-rebond (Debounce) logiciel simple : 200ms
    	        if (interrupt_time - last_interrupt_time > 200)
    	        {
    	            // Action à faire, par exemple :
    	            touche_TTP = 1;
    	        }
    	        last_interrupt_time = interrupt_time;
    }
    if(GPIO_Pin == TTP_1_Pin){
        	 // Ton code ici (ex: changer une variable d'état pour passer à l'étape suivante)
        	        // ATTENTION : Ne mets JAMAIS de HAL_Delay() ou de fonctions d'écriture LCD longues ici !

        	        static uint32_t last_interrupt_time = 0;
        	        uint32_t interrupt_time = HAL_GetTick();

        	        // Anti-rebond (Debounce) logiciel simple : 200ms
        	        if (interrupt_time - last_interrupt_time > 200)
        	        {
        	            // Action à faire, par exemple :
        	            touche_TTP = 2;
        	        }
        	        last_interrupt_time = interrupt_time;
        }


}

/* USER CODE END 4 */
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


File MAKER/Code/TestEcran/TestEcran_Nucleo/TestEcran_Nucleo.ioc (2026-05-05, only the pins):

Mcu.UserName=STM32L476RGTx
PA2.GPIO_Label=USART_TX
PA2.Signal=USART2_TX
PA3.GPIO_Label=USART_RX
PA3.Signal=USART2_RX
PA5.GPIO_Label=LD2 [green Led]
PA5.Signal=GPIO_Output
PA9.GPIO_Label=LCD_DC
PA9.Signal=GPIO_Output
PB13.Signal=SPI2_SCK
PB14.Signal=SPI2_MISO
PB15.Signal=SPI2_MOSI
PB6.GPIO_Label=LCD_CS
PB6.Signal=GPIO_Output
PB8.GPIO_Label=TTP_0
PB8.Signal=GPXTI8
PC13.GPIO_Label=B1 [Blue PushButton]
PC13.Signal=GPXTI13
PC7.GPIO_Label=LCD_RES
PC7.Signal=GPIO_Output

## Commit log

2026-01-18 Insert Gantt chart for project planning
    Added a Gantt chart to the project planning section.
2026-02-16 Update README with magnetic sensors link and remove RFID
2026-03-09 Réorganisation du git
    [Schématique_PCB.kicad_pcb, Schématique_PCB.kicad_sch]
2026-03-09 Réorganisation fichiers Kicad
    [Schématique_PCB.kicad_pcb, Schématique_PCB.kicad_sch]
2026-03-09 Journal de Bord
2026-03-09 Update README with link to reed switch
    Added a link to the reed switch in the README.
2026-03-09 "Update suppression de fichiers"
    [Schématique_PCB.kicad_pcb, Schématique_PCB.kicad_sch]
2026-04-02 MAJ PCB 4 Couches
    [Schématique_PCB.kicad_pcb, Schématique_PCB_basique.kicad_pcb]
2026-04-13 MAJ Prog de test avec Nb aléatoire
2026-05-05 MAJ Ecran avec 2 boutons
    [Schématique_PCB.csv]
2026-05-05 Reorganisation des fichiers + MAJ journal de bord
2026-05-05 Update README with sensor replacement details
    Added a note about replacing RFID cards with TTP223 touch sensors and updated the material list.

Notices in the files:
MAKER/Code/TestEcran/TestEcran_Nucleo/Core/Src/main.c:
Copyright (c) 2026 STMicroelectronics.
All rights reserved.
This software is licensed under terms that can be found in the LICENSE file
